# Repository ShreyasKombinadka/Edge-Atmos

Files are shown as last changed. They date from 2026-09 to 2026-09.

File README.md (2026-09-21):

## **Edge Atmos**

A local weather station built with no HAL and all custom drivers and libraries built from bare-metal register level coding.

## Overview
- Built on STM32 board with no HAL.
- All the driver and libraries are custom built.

## Status
- [ ] Firmware
- [ ] Hardware 
- [ ] Completed

## Libraries built
1. I2C driver
2. LCD1602 driver
3. ASCII conversion library
4. AHT10 Temperature and humidity sensor driver
5. BMP280 Pressure sensor driver
6. GPIO driver
7. SPI driver
8. W25Q32 Flash memory driver
9. ST7789LCD TFT display driver
10. Font bitmap file

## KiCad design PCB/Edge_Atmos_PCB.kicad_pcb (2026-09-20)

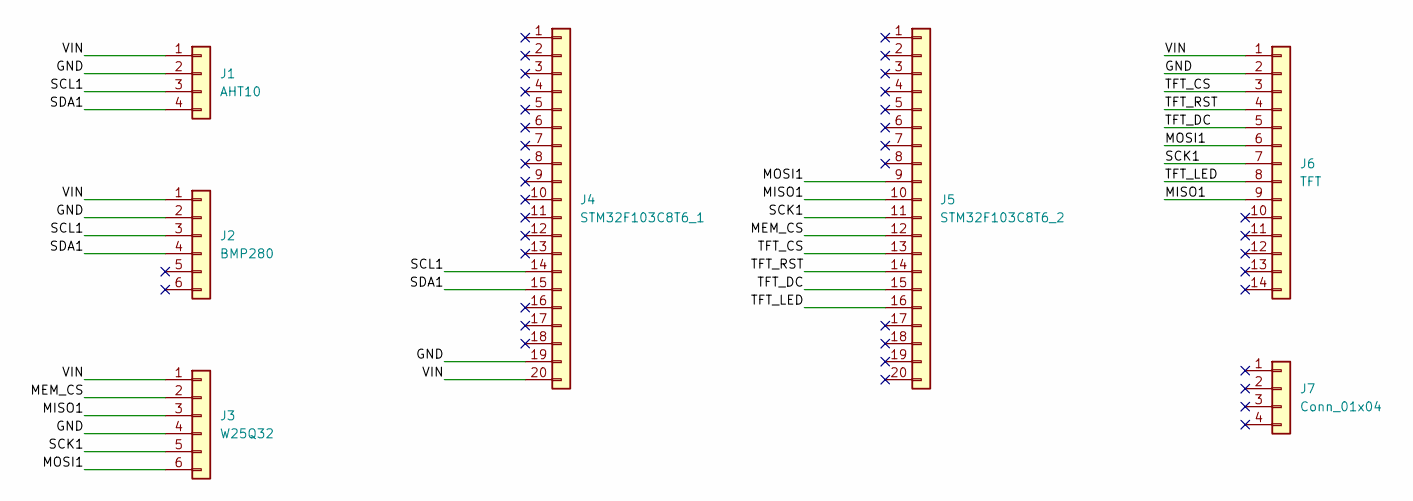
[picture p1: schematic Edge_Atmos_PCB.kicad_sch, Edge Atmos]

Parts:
J1: AHT10; PinSocket_1x04_P2.54mm_Vertical
J2: BMP280; PinSocket_1x06_P2.54mm_Vertical
J3: W25Q32; PinSocket_1x06_P2.54mm_Vertical
J4: STM32F103C8T6_1; PinSocket_1x20_P2.54mm_Vertical
J5: STM32F103C8T6_2; PinSocket_1x20_P2.54mm_Vertical
J6: TFT; PinSocket_1x14_P2.54mm_Vertical
J7: Conn_01x04; PinSocket_1x04_P2.54mm_Vertical

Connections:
/GND: J1.2, J2.2, J3.4, J4.19, J6.2
/MEM_CS: J3.2, J5.12
/MISO1: J3.3, J5.10, J6.9
/MOSI1: J3.6, J5.9, J6.6
/SCK1: J3.5, J5.11, J6.7
/SCL1: J1.3, J2.3, J4.14
/SDA1: J1.4, J2.4, J4.15
/TFT_CS: J5.13, J6.3
/TFT_DC: J5.15, J6.5
/TFT_LED: J5.16, J6.8
/TFT_RST: J5.14, J6.4
/VIN: J1.1, J2.1, J3.1, J4.20, J6.1

Board: 2 copper layers, 7 parts (2 on the bottom side), 12 nets, no tracks yet.

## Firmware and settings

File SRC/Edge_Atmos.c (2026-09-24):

#include <stdint.h>

#include "I2C_MS/I2C1.h"
#include "SPI_MS/SPI1.h"
#include "AHT10_MS/AHT10.h"
#include "BMP280_MS/BMP280.h"
#include "W25Q32_MS/W25Q32.h"
#include "ASCII_MS/ASCII.h"
#include "ST7789LCD_MS/ST7789LCD.h"
#include "COLOR_MS/COLOR.h"
#include "DYNAWEAT_MS/DYNAWEAT.h"

#define STM32F103xB
#include "STM32F103_CMSIS/stm32f1xx.h"

// Pins and Ports
#define MEM_CS 4         // Flash CS
#define MEM_CS_PORT 'A'  // Flash CS port
#define TFT_CS 3         // TFT display CS
#define TFT_CS_PORT 'A'  // TFT display CS port
#define TFT_DC 1         // TFT display DC
#define TFT_DC_PORT 'A'  // TFT display DC port
#define TFT_RST 2        // TFT display RST
#define TFT_RST_PORT 'A' // TFT display RST port
#define TFT_LED 0        // TFT display LED
#define TFT_LED_PORT 'A' // TFT display LED port
#define DISPLAY_ORIEN 3  // TFT display orientation/rotation

int main(void)
{
    // Initialisations of drivers
    i2c1_init();     // I2C initialisation
    spi1_init(3, 0); // SPI initialisation

    aht10_init();                          // AHT10 sensor initialisation
    uint8_t FACTORY_CALIBRATION_DATA[24];  // BMP280 factory calibration data
    bmp280_init(FACTORY_CALIBRATION_DATA); // BMP280 sensor initialisation

    st7789lcd_pinset(TFT_CS, TFT_CS_PORT, TFT_DC, TFT_DC_PORT, TFT_RST, TFT_RST_PORT, TFT_LED, TFT_LED_PORT); // Display pin configuration
    st7789lcd_dispset(DISPLAY_ORIEN, 320, 240);                                                               // Display settings
    st7789lcd_init();                                                                                         // TFT display initialisation

    // Display setup
    st7789lcd_clearall(MS_WHITE_16);
    st7789lcd_settext(16, 12);

    st7789lcd_setbox(1, 0, 60, 0, 320);
    st7789lcd_setbox(2, 60, 150, 0, 150);
    st7789lcd_setbox(3, 60, 150, 150, 250);
    st7789lcd_setbox(4, 60, 150, 250, 320);
    st7789lcd_setbox(5, 150, 240, 0, 320);

    st7789lcd_inbox(1);
    st7789lcd_fillbox(MS_GREEN_16);
    st7789lcd_print("EDGE ATMOS", 10, 40, MS_BRIGHT_RED_16, 2);

    st7789lcd_inbox(2);
    st7789lcd_fillbox(MS_YELLOW_16);
    st7789lcd_print("TEMPERATURE", 10, 10, MS_BLACK_16, 1);
    st7789lcd_colrst();
    st7789lcd_print("PRESURE", 10, 10, MS_BLACK_16, 1);
    st7789lcd_colrst();
    st7789lcd_print("HUMIDITY", 10, 10, MS_BLACK_16, 1);

    st7789lcd_inbox(4);
    st7789lcd_fillbox(MS_CYAN_16);
    st7789lcd_print("'", 10, 10, MS_BLACK_16, 1);
    st7789lcd_colrst();
    st7789lcd_print("hpa", 10, 10, MS_BLACK_16, 1);
    st7789lcd_colrst();
    st7789lcd_print("%", 10, 10, MS_BLACK_16, 1);

    st7789lcd_inbox(5);
    st7789lcd_fillbox(MS_ORANGE_16);
    st7789lcd_print("THIS IS THE 5TH WINDOW FOR SOME REASON", 10, 10, MS_BLACK_16, 1);

    st7789lcd_inbox(3);
    st7789lcd_fillbox(MS_LIGHT_GRAY_16);

    while (1)
    {
        float aht_temp = 0;
        float bmp_temp = 0;
        float humi = 0;
        float pres = 0;
        aht10_read(&aht_temp, &humi);
        bmp280_read(FACTORY_CALIBRATION_DATA, &pres, &bmp_temp);

        uint8_t aht_temp_char_arr[6];
        uint8_t bmp_temp_char_arr[6];
        uint8_t humi_char_arr[6];
        uint8_t pres_char_arr[6];
        num_float4digi_ascii(aht_temp, aht_temp_char_arr);
        num_float4digi_ascii(bmp_temp, bmp_temp_char_arr);
        num_float4digi_ascii(humi, humi_char_arr);
        num_float4digi_ascii(pres, pres_char_arr);

        uint16_t temp_color = dynaweat_temp16(bmp_temp);
        uint16_t pres_color = dynaweat_pres16(pres);
        uint16_t humi_color = dynaweat_humi16(humi);

        st7789lcd_addrst();
        st7789lcd_print(bmp_temp_char_arr, 10, 10, temp_color, 1);
        st7789lcd_colrst();
        st7789lcd_print(pres_char_arr, 10, 10, pres_color, 1);
        st7789lcd_colrst();
        st7789lcd_print(humi_char_arr, 10, 10, humi_color, 1);
    }
}

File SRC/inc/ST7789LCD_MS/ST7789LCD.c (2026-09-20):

#include "ST7789LCD.h"
#include "../SPI_MS/SPI1.h"
#include "../GPIO_MS/GPIO.h"
#include "../FONT_MS/BITMAP.h"

#include <stdint.h>

static struct ST7789LCD st7789lcd;

void st7789lcd_pinset(uint8_t CS, uint8_t CS_PORT, uint8_t DC, uint8_t DC_PORT, uint8_t RST, uint8_t RST_PORT, uint8_t LED, uint8_t LED_PORT) // TFT(ST7789) LCD display pin connections
{
    st7789lcd.CS = CS;
    st7789lcd.CS_PORT = CS_PORT;
    st7789lcd.DC = DC;
    st7789lcd.DC_PORT = DC_PORT;
    st7789lcd.RST = RST;
    st7789lcd.RST_PORT = RST_PORT;
    st7789lcd.LED = LED;
    st7789lcd.LED_PORT = LED_PORT;
}

void st7789lcd_dispset(uint8_t ROTATION, uint16_t HEIGHT, uint16_t WIDTH) // TFT(ST7789) LCD display parameters
{
    st7789lcd.ROTATION = ROTATION;
    st7789lcd.HEIGHT = HEIGHT;
    st7789lcd.WIDTH = WIDTH;
}

void st7789lcd_init() // TFT(ST7789) LCD display initialisation
{
    gpio_en(st7789lcd.DC_PORT);  // Enable DC pin port
    gpio_en(st7789lcd.RST_PORT); // Enable RST pin port

    gpio_setup(st7789lcd.DC, st7789lcd.DC_PORT, 3, 0);   // Set as output at 2MHz push pull mode
    gpio_setup(st7789lcd.RST, st7789lcd.RST_PORT, 3, 0); // Set as output at 2MHz push pull mode

    spi1_slaveset(st7789lcd.CS, st7789lcd.CS_PORT, 3); // Set CS pin

    if (!(st7789lcd.LED_PORT == 'V' || st7789lcd.LED_PORT == 'v')) // If the LED pin is not VCC
    {
        gpio_en(st7789lcd.LED_PORT);                         // Enable LED pin port
        gpio_setup(st7789lcd.LED, st7789lcd.LED_PORT, 3, 0); // Set as output at 2MHz push pull mode
        gpio_setreset(st7789lcd.LED, st7789lcd.LED_PORT, 1); // Set LED pin
    }

    gpio_setreset(st7789lcd.RST, st7789lcd.RST_PORT, 0); // Reset RST pin
    for (volatile int i = 0; i <= 160; i++)              // Delay of ~50mS
        for (volatile int j = 0; j <= 160; j++)
            ;
    gpio_setreset(st7789lcd.RST, st7789lcd.RST_PORT, 1); // Set RST pin

    spi1_slaveselect(st7789lcd.CS, st7789lcd.CS_PORT, 1); // Select slave

    // Software Reset
    gpio_setreset(st7789lcd.DC, st7789lcd.DC_PORT, 0); // Reset DC pin for cmd
    spi1_8w1byte(0x01);                                // Software Reset cmd
    for (volatile int i = 0; i <= 1100; i++)           // Delay of ~150mS
        for (volatile int j = 0; j <= 1100; j++)
            ;

    // Sleep Out
    spi1_8w1byte(0x11);                      // Sleep Out cmd
    for (volatile int i = 0; i <= 1100; i++) // Delay of ~150mS
        for (volatile int j = 0; j <= 1100; j++)
            ;

    st7789lcd_setup(); // Sets display orientation and RGB color path

    // Porch Setting
    gpio_setreset(st7789lcd.DC, st7789lcd.DC_PORT, 0); // Reset DC pin for cmd
    spi1_8w1byte(0xB2);                                // Porch Setting cmd
    gpio_setreset(st7789lcd.DC, st7789lcd.DC_PORT, 1); // Set DC pin for data
    spi1_8w1byte(0x0C);                                // Data Parameter
    spi1_8w1byte(0x0C);                                // Data Parameter
    spi1_8w1byte(0x00);                                // Data Parameter
    spi1_8w1byte(0x33);                                // Data Parameter
    spi1_8w1byte(0x33);                                // Data Parameter

    // Gate Control
    gpio_setreset(st7789lcd.DC, st7789lcd.DC_PORT, 0); // Reset DC pin for cmd
    spi1_8w1byte(0xB7);                                // Gate Control cmd
    gpio_setreset(st7789lcd.DC, st7789lcd.DC_PORT, 1); // Set DC pin for data
    spi1_8w1byte(0x35);                                // Data Parameter

    // VCOM Setting
    gpio_setreset(st7789lcd.DC, st7789lcd.DC_PORT, 0); // Reset DC pin for cmd
    spi1_8w1byte(0xBB);                                // VCOM Setting cmd
    gpio_setreset(st7789lcd.DC, st7789lcd.DC_PORT, 1); // Set DC pin for data
    spi1_8w1byte(0x19);                                // Data Parameter

    // VRH Set
    gpio_setreset(st7789lcd.DC, st7789lcd.DC_PORT, 0); // Reset DC pin for cmd
    spi1_8w1byte(0xC3);                                // VRH Set cmd
    gpio_setreset(st7789lcd.DC, st7789lcd.DC_PORT, 1); // Set DC pin for data
    spi1_8w1byte(0x12);                                // Data Parameter

    // VDV Set
    gpio_setreset(st7789lcd.DC, st7789lcd.DC_PORT, 0); // Reset DC pin for cmd
    spi1_8w1byte(0xC4);                                // VDV Set cmd
    gpio_setreset(st7789lcd.DC, st7789lcd.DC_PORT, 1); // Set DC pin for data
    spi1_8w1byte(0x20);                                // Data Parameter

    // Frame Rate Control in Normal Mode
    gpio_setreset(st7789lcd.DC, st7789lcd.DC_PORT, 0); // Reset DC pin for cmd
    spi1_8w1byte(0xC6);                                // Frame Rate Control in Normal Mode cmd
    gpio_setreset(st7789lcd.DC, st7789lcd.DC_PORT, 1); // Set DC pin for data
    spi1_8w1byte(0x0F);                                // Data Parameter(60Hz refresh rate)

    // Power Control 1
    gpio_setreset(st7789lcd.DC, st7789lcd.DC_PORT, 0); // Reset DC pin for cmd
    spi1_8w1byte(0xD0);                                // Power Control 1 cmd
    gpio_setreset(st7789lcd.DC, st7789lcd.DC_PORT, 1); // Set DC pin for data
    spi1_8w1byte(0xA4);                                // Data Parameter
    spi1_8w1byte(0xA1);                                // Data Parameter

    // Display Inversion OFF
    gpio_setreset(st7789lcd.DC, st7789lcd.DC_PORT, 0); // Reset DC pin for cmd
    spi1_8w1byte(0x20);                                // Display Inversion OFF cmd
    for (volatile int i = 0; i <= 80; i++)             // Delay of ~10mS
        for (volatile int j = 0; j <= 80; j++)
            ;

    // Normal Display Mode ON
    spi1_8w1byte(0x13);                    // Normal Display Mode ON cmd
    for (volatile int i = 0; i <= 80; i++) // Delay of ~10mS
        for (volatile int j = 0; j <= 80; j++)
            ;

    // Display ON
    spi1_8w1byte(0x29);                     // Display ON cmd
    for (volatile int i = 0; i <= 160; i++) // Delay of ~50mS
        for (volatile int j = 0; j <= 160; j++)
            ;

    spi1_slaveselect(st7789lcd.CS, st7789lcd.CS_PORT, 0); // De-select slave device
}
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

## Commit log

2026-04-04 Code to read from temp sensor using I2C communication
2026-04-12 Implimented a custom i2c library and used it
2026-06-13 I2C and LCD libraries are functional on hardware
2026-06-17 Working on AHT10 sensor integration
2026-06-17 Completed AHT10 sensor intigration
2026-06-18 Fixed some unwanted delays
    [AHT10.c, BMP280.c, Edge_Atmos.c]
2026-06-18 Working on BMP280 intigration and solving ascii lib problems
    [Edge_Atmos.c]
2026-06-20 Working on display functions and sensor intigration
2026-06-21 Solved out of bounds wright for pressure values charrecter buffer
    [AHT10.c, BMP280.c, Edge_Atmos.c]
2026-06-21 BMP280 sensor intigration is done
2026-06-22 Completed sensor intigration
2026-06-23 Building SPI library
2026-06-24 Updated SPI lib
2026-06-24 Working on the SPI and flash memory library
2026-06-30 Writing a GPIO driver
2026-06-30 Updating drivers with intigration of GPIO driver and removing unwanted functions
2026-07-25 Got the TFT display working it wasnt even a code problem it was LED pins physical contact porblem...
    [Edge_Atmos.c, GPIO.c, I2C1.c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]
2026-07-29 Working on TFT display print function
2026-08-15 Solved the display rotation bug and the TFT display now works in all rotations porperly
    [Edge_Atmos.c, ST7789LCD.c]
2026-08-19 Completed TFT display driver
2026-08-23 Working on adding dynamic weather value color library
    [Edge_Atmos_PCB.kicad_pcb, Edge_Atmos_PCB.kicad_sch]
2026-09-05 Adding box structure to display library
    [Edge_Atmos_PCB.kicad_pcb, Edge_Atmos_PCB.kicad_sch]
2026-09-20 Increased number of windows
    [Edge_Atmos_PCB.kicad_pcb]
2026-09-24 Updating flash memory driver for intigration with EALGO
2026-10-02 Started intigration of interupt on I2C
2026-10-05 Updating I2C driver
2026-10-08 Working on I2C interupt intigration
2026-10-09 Working on interupt intigration on I2C driver
2026-10-18 Working on interupt intigration to I2C
2026-10-22 Working on interupt intigration to I2C driver
2026-10-25 Local test on ring buffer for I2C driver
